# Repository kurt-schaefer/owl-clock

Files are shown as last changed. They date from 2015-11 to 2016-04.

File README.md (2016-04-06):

# owl-clock
2015 Christmas Project

I built six of these owl clocks in the run up to Christmas 2015.
It uses edge lit acrylic sheets to act as psudo Nixie Tubes. The clock uses an ATMEGA328p at it's core. The display is powered but 40 [WS2812b] (https://www.adafruit.com/datasheets/WS2812B.pdf) RGB leds.
I have a [blog post] (https://retrotechjournal.com/2016/04/04/plexitube-owl-clock/) with a longer write up of the project.

Image
-----------

Owl Clock

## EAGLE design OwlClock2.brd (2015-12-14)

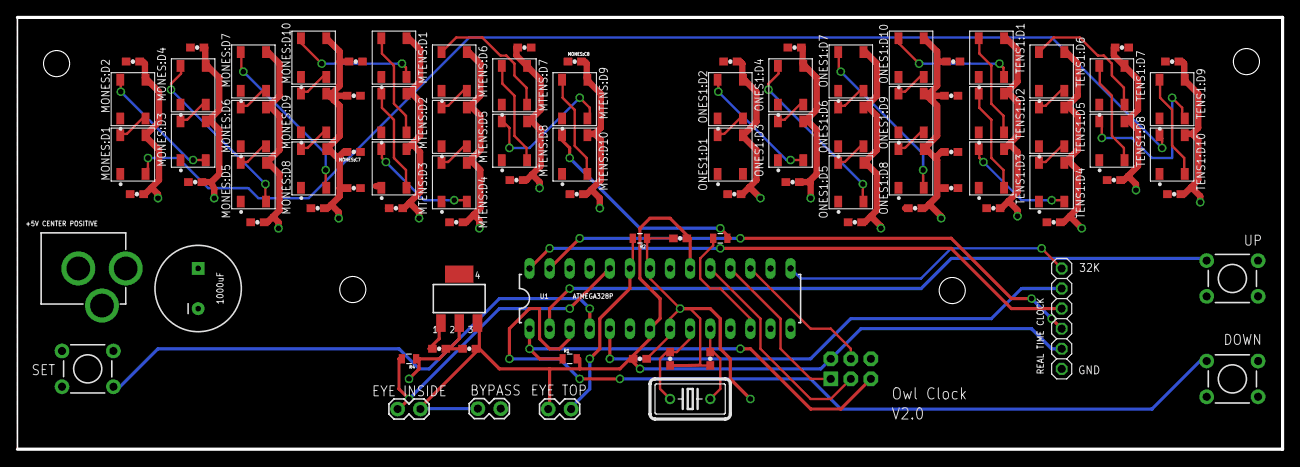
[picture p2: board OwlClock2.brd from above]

Board: 2 copper layers, 160.0 x 54.6 mm, 99 parts (0 on the bottom side), 59 nets.

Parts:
C1, C2: 22pF; 0603-CAP
C3, C4: 0.1uF; 0603-CAP
C5: 1000uF; CPOL-RADIAL-1000UF-25V
C6, C7: 1uF; 0603-CAP
DOWN: SWITCH-MOMENTARY-2PTH; TACTILE-PTH
IC1: MCP1703DB; SOT223
J1: AVR_SPI_PRG_6NS; 2X3-NS
J2: POWER_JACKPTH; POWER_JACK_PTH
JP1: REAL TIME CLOCK; 1X06
MONES:C1, MONES:C2, MONES:C3, MONES:C4, MONES:C5, MONES:C6, MONES:C7, MONES:C8: 0.1uF; 0603-CAP
MONES:D1, MONES:D2, MONES:D3, MONES:D4, MONES:D5, MONES:D6, MONES:D7, MONES:D8, MONES:D9, MONES:D10: WS2812B
MTENS:C1, MTENS:C2, MTENS:C3, MTENS:C4, MTENS:C5, MTENS:C6, MTENS:C7, MTENS:C8: 0.1uF; 0603-CAP
MTENS:D1, MTENS:D2, MTENS:D3, MTENS:D4, MTENS:D5, MTENS:D6, MTENS:D7, MTENS:D8, MTENS:D9, MTENS:D10: WS2812B
ONES1:C1, ONES1:C2, ONES1:C3, ONES1:C4, ONES1:C5, ONES1:C6, ONES1:C7, ONES1:C8: 0.1uF; 0603-CAP
ONES1:D1, ONES1:D2, ONES1:D3, ONES1:D4, ONES1:D5, ONES1:D6, ONES1:D7, ONES1:D8, ONES1:D9, ONES1:D10: WS2812B
PHOTO_INSIDE: M02LOCK; 1X02_LOCK
PHOTO_TOP: M02LOCK; 1X02_LOCK
Q1: 16Mhz; HC18U-V
R1, R2, R4: 10k; 0805
R3: 470; 0805
SET: SWITCH-MOMENTARY-2PTH; TACTILE-PTH
SUPPLY_BYPASS: M02LOCK; 1X02_LOCK
TENS1:C1, TENS1:C2, TENS1:C3, TENS1:C4, TENS1:C5, TENS1:C6, TENS1:C7, TENS1:C8: 0.1uF; 0603-CAP
TENS1:D1, TENS1:D2, TENS1:D3, TENS1:D4, TENS1:D5, TENS1:D6, TENS1:D7, TENS1:D8, TENS1:D9, TENS1:D10: WS2812B
U1: ATMEGA328P_PDIP; DIL28-3
U$1, U$2, U$3, U$4: STAND-OFF
UP: SWITCH-MOMENTARY-2PTH; TACTILE-PTH

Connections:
32K: JP1.1, U1.15
!RESET: J1.5, R1.1, U1.1
ADC0: PHOTO_TOP.1, R2.2, U1.23
ADC1: PHOTO_INSIDE.1, R4.2, U1.24
DP0: U1.2, UP.1
DP1: DOWN.1, U1.3
DP2: SET.1, U1.4
GND: C1.1, C2.1, C3.2, C4.2, C5.2, C6.1, C7.1, DOWN.3, IC1.2, J1.6, J2.GND, J2.GNDBREAK, JP1.6, MONES:C1.2, MONES:C2.2, MONES:C3.2, MONES:C4.2, MONES:C5.2, MONES:C6.2, MONES:C7.2, MONES:C8.2, MONES:D1.3, MONES:D2.3, MONES:D3.3, MONES:D4.3, MONES:D5.3, MONES:D6.3, MONES:D7.3, MONES:D8.3, MONES:D9.3, MONES:D10.3, MTENS:C1.2, MTENS:C2.2, MTENS:C3.2, MTENS:C4.2, MTENS:C5.2, MTENS:C6.2, MTENS:C7.2, MTENS:C8.2, MTENS:D1.3, MTENS:D2.3, MTENS:D3.3, MTENS:D4.3, MTENS:D5.3, MTENS:D6.3, MTENS:D7.3, MTENS:D8.3, MTENS:D9.3, MTENS:D10.3, ONES1:C1.2, ONES1:C2.2, ONES1:C3.2, ONES1:C4.2, ONES1:C5.2, ONES1:C6.2, ONES1:C7.2, ONES1:C8.2, ONES1:D1.3, ONES1:D2.3, ONES1:D3.3, ONES1:D4.3, ONES1:D5.3, ONES1:D6.3, ONES1:D7.3, ONES1:D8.3, ONES1:D9.3, ONES1:D10.3, R2.1, R4.1, SET.3, TENS1:C1.2, TENS1:C2.2, TENS1:C3.2, TENS1:C4.2, TENS1:C5.2, TENS1:C6.2, TENS1:C7.2, TENS1:C8.2, TENS1:D1.3, TENS1:D2.3, TENS1:D3.3, TENS1:D4.3, TENS1:D5.3, TENS1:D6.3, TENS1:D7.3, TENS1:D8.3, TENS1:D9.3, TENS1:D10.3, U1.8, U1.22, UP.3
MISO: J1.1, U1.18
MONES:N$1: MONES:D2.4, MONES:D3.2
MONES:N$5: MONES:D1.4, MONES:D2.2
MONES:N$6: MONES:D3.4, MONES:D4.2
MONES:N$7: MONES:D4.4, MONES:D5.2
MONES:N$9: MONES:D5.4, MONES:D6.2
MONES:N$10: MONES:D6.4, MONES:D7.2
MONES:N$12: MONES:D7.4, MONES:D8.2
MONES:N$13: MONES:D8.4, MONES:D9.2
MONES:N$15: MONES:D9.4, MONES:D10.2
MOSI: J1.4, U1.17
MTENS:N$1: MTENS:D2.4, MTENS:D3.2
MTENS:N$5: MTENS:D1.4, MTENS:D2.2
MTENS:N$6: MTENS:D3.4, MTENS:D4.2
MTENS:N$7: MTENS:D4.4, MTENS:D5.2
MTENS:N$9: MTENS:D5.4, MTENS:D6.2
MTENS:N$10: MTENS:D6.4, MTENS:D7.2
MTENS:N$12: MTENS:D7.4, MTENS:D8.2
MTENS:N$13: MTENS:D8.4, MTENS:D9.2
MTENS:N$15: MTENS:D9.4, MTENS:D10.2
M_ONES_OUT: MONES:D1.2, TENS1:D10.4
M_TENS_IN: MTENS:D10.4, R3.2
unnamed: MONES:D10.4, MTENS:D1.2
unnamed: R3.1, U1.12
unnamed: ONES1:D10.4, TENS1:D1.2
unnamed: C1.2, Q1.2, U1.9
unnamed: C2.2, Q1.1, U1.10
ONES1:N$1: ONES1:D2.4, ONES1:D3.2
ONES1:N$5: ONES1:D1.4, ONES1:D2.2
ONES1:N$6: ONES1:D3.4, ONES1:D4.2
ONES1:N$7: ONES1:D4.4, ONES1:D5.2
ONES1:N$9: ONES1:D5.4, ONES1:D6.2
ONES1:N$10: ONES1:D6.4, ONES1:D7.2
ONES1:N$12: ONES1:D7.4, ONES1:D8.2
ONES1:N$13: ONES1:D8.4, ONES1:D9.2
ONES1:N$15: ONES1:D9.4, ONES1:D10.2
SCK: J1.3, U1.19
SCL: JP1.3, U1.28
SDA: JP1.4, U1.27
SQW: JP1.2, U1.5
TENS1:N$1: TENS1:D2.4, TENS1:D3.2
TENS1:N$5: TENS1:D1.4, TENS1:D2.2
TENS1:N$6: TENS1:D3.4, TENS1:D4.2
TENS1:N$7: TENS1:D4.4, TENS1:D5.2
TENS1:N$9: TENS1:D5.4, TENS1:D6.2
TENS1:N$10: TENS1:D6.4, TENS1:D7.2
TENS1:N$12: TENS1:D7.4, TENS1:D8.2
TENS1:N$13: TENS1:D8.4, TENS1:D9.2
TENS1:N$15: TENS1:D9.4, TENS1:D10.2
VCC: C5.1, C7.2, IC1.1, J2.PWR, MONES:C1.1, MONES:C2.1, MONES:C3.1, MONES:C4.1, MONES:C5.1, MONES:C6.1, MONES:C7.1, MONES:C8.1, MONES:D1.1, MONES:D2.1, MONES:D3.1, MONES:D4.1, MONES:D5.1, MONES:D6.1, MONES:D7.1, MONES:D8.1, MONES:D9.1, MONES:D10.1, MTENS:C1.1, MTENS:C2.1, MTENS:C3.1, MTENS:C4.1, MTENS:C5.1, MTENS:C6.1, MTENS:C7.1, MTENS:C8.1, MTENS:D1.1, MTENS:D2.1, MTENS:D3.1, MTENS:D4.1, MTENS:D5.1, MTENS:D6.1, MTENS:D7.1, MTENS:D8.1, MTENS:D9.1, MTENS:D10.1, ONES1:C1.1, ONES1:C2.1, ONES1:C3.1, ONES1:C4.1, ONES1:C5.1, ONES1:C6.1, ONES1:C7.1, ONES1:C8.1, ONES1:D1.1, ONES1:D2.1, ONES1:D3.1, ONES1:D4.1, ONES1:D5.1, ONES1:D6.1, ONES1:D7.1, ONES1:D8.1, ONES1:D9.1, ONES1:D10.1, SUPPLY_BYPASS.2, TENS1:C1.1, TENS1:C2.1, TENS1:C3.1, TENS1:C4.1, TENS1:C5.1, TENS1:C6.1, TENS1:C7.1, TENS1:C8.1, TENS1:D1.1, TENS1:D2.1, TENS1:D3.1, TENS1:D4.1, TENS1:D5.1, TENS1:D6.1, TENS1:D7.1, TENS1:D8.1, TENS1:D9.1, TENS1:D10.1
VSS: C3.1, C4.1, C6.2, IC1.3, J1.2, JP1.5, PHOTO_INSIDE.2, PHOTO_TOP.2, R1.2, SUPPLY_BYPASS.1, U1.7, U1.20

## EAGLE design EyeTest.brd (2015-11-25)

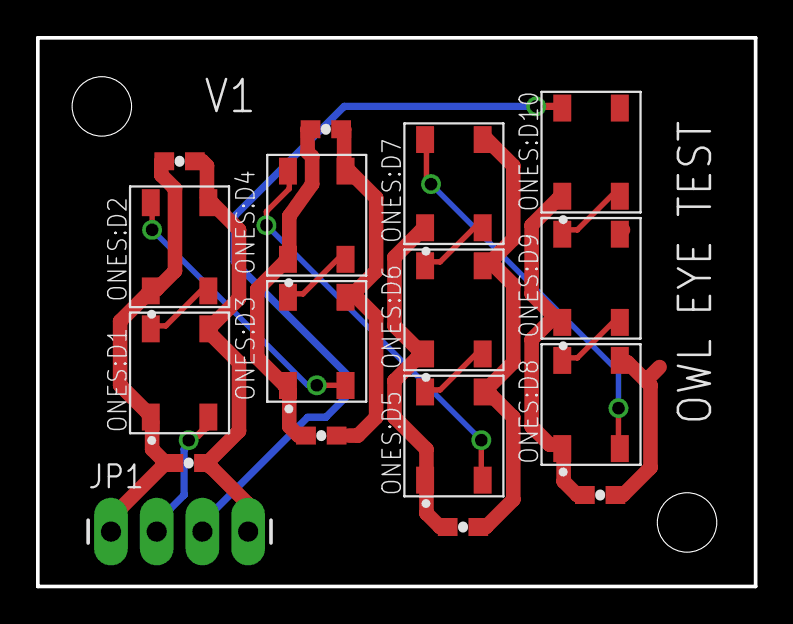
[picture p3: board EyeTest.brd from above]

Board: 2 copper layers, 39.9 x 30.5 mm, 19 parts (0 on the bottom side), 13 nets.

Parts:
JP1: 1X04_LONGPADS
ONES:C1, ONES:C2, ONES:C3, ONES:C4, ONES:C5, ONES:C6: 0.1uF; 0603-CAP
ONES:D1, ONES:D2, ONES:D3, ONES:D4, ONES:D5, ONES:D6, ONES:D7, ONES:D8, ONES:D9, ONES:D10: WS2812B
U$1, U$2: STAND-OFF

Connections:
DIN: JP1.3, ONES:D10.4
DOUT: JP1.2, ONES:D1.2
GND: JP1.4, ONES:C1.2, ONES:C2.2, ONES:C3.2, ONES:C4.2, ONES:C5.2, ONES:C6.2, ONES:D1.3, ONES:D2.3, ONES:D3.3, ONES:D4.3, ONES:D5.3, ONES:D6.3, ONES:D7.3, ONES:D8.3, ONES:D9.3, ONES:D10.3
ONES:N$1: ONES:D2.4, ONES:D3.2
ONES:N$5: ONES:D1.4, ONES:D2.2
ONES:N$6: ONES:D3.4, ONES:D4.2
ONES:N$7: ONES:D4.4, ONES:D5.2
ONES:N$9: ONES:D5.4, ONES:D6.2
ONES:N$10: ONES:D6.4, ONES:D7.2
ONES:N$12: ONES:D7.4, ONES:D8.2
ONES:N$13: ONES:D8.4, ONES:D9.2
ONES:N$15: ONES:D9.4, ONES:D10.2
VCC: JP1.1, ONES:C1.1, ONES:C2.1, ONES:C3.1, ONES:C4.1, ONES:C5.1, ONES:C6.1, ONES:D1.1, ONES:D2.1, ONES:D3.1, ONES:D4.1, ONES:D5.1, ONES:D6.1, ONES:D7.1, ONES:D8.1, ONES:D9.1, ONES:D10.1

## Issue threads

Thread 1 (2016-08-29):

Update license please

burdickjp, 2016-08-29:
Hey, Kurt!
I want to make DROs for me mill and lathe using plexitubes because they're awesome. I appreciate that you've got a github for the project, because it allows me to link back to it and provide proper attribution.
I noticed that your license is software related and this is a hardware project.
Could you switch to a license compliant with the open source hardware guidelines?
http://www.oshwa.org/

I tend to use the Cern OHL:
http://www.ohwr.org/projects/cernohl/wiki

Thank you, again for documenting such an awesome project and taking the time to releasing it as open source.

kurt-schaefer, 2016-08-30:
Wow, I'd love to see a mill with Plexitube DRO's!   That sounds fun.   Yes sorry I was mostly using github for the software side.  I've never released open source hardware before.  I'll read though the guidelines and update the license.  I wrote the build up as a "oh I built this" not as a full on "here's every detail on how to built it yourself".  So just be aware of that.   Refining/documenting/testing a project to a "this is DIY instructions" level is a  project unto itself.  Doing these Christmas Projects I always have a super short schedule so time for iteration is pretty much zero.

Let me know if you manage to get something up and running!   If you get it written up I'd be happy to add a link over to it from my blog. I'd love to see some other projects spring from this one.

I'm super busy right this second, but Wed. night I should have time to read up on the license stuff and update it.  I should know about that stuff anyway since I do a modest amount of hardware design.

burdickjp, 2016-08-30:
Thank you, and glad I can help with the licensing.
Looking through Oshwa can be daunting, but in general it just comes down to a preference for working files rather than distribution files. A good example is CAD models rather than STLs for 3d printing parts. STEP files are a good compromise because they can be altered by most CAD programs, but STLs are lossy and don't preserve features.
If you're worried front-to-back about a permissive license which provides a decent blanket to all things you could go with a creative commons license. I prefer stricter OHL licenses because of their focus on releasing working, usable models.

kurt-schaefer, 2016-09-03:
Ok, I added the cernohl.  Let me know how your project goes!

Closed 2016-09-03.

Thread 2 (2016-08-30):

Day of the Week computation not working

kurt-schaefer, 2016-08-30:
I noticed that Mother's day/Father's day were not working.  Further testing of the code in an Arduino simulator confirms that the days of the week code is failing under single precision math.  Since I don't think I'm going to update everyone's clocks I don't know as I'm going to go though the trouble of getting this to work, but I'll file this to document the issue.

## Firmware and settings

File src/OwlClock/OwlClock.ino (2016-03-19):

#include <Adafruit_NeoPixel.h> // https://github.com/adafruit/Adafruit_NeoPixel
#include <DS3232RTC.h>         // http://github.com/JChristensen/DS3232RTC
#include <Time.h>              // http://www.arduino.cc/playground/Code/Time
#include <Wire.h>              // http://arduino.cc/en/Reference/Wire (included with Arduino IDE)
#include <EEPROM.h>
#include "Declarations.h"

// My helper lib that has moon and holiday code in it.
extern "C" {
#include "AstronomicalCalculations.h"
}

#define LIGHT_SENSOR_TOP_ANALOG_IN     A0
#define LIGHT_SENSOR_INSIDE_ANALOG_IN  A1
#define LED_COUNT 40

#define LED_DIG_OUT        6

#define NOT_RUNNING_ON_UNO

#ifdef NOT_RUNNING_ON_UNO
    #define DEBUG_PRINT(x)    Serial.print(x)
    #define DEBUG_PRINTLN(x)  Serial.println(x)
#else
    #define DEBUG_PRINT(x)    {}  
    #define DEBUG_PRINTLN(x ) {} 
#endif

#ifdef RUNNING_ON_UNO
    #define SWITCH_UP_DIG_IN   2
    #define SWITCH_DOWN_DIG_IN 3
    #define SWITCH_SET_DIG_IN  4
#else
// This has up/down reversed from what is silscreened on the boards, but this
// is the "right" way around in term of feel.
    #define SWITCH_UP_DIG_IN   1
    #define SWITCH_DOWN_DIG_IN 0
    #define SWITCH_SET_DIG_IN  2
#endif

// Neo pixel interface for all the LEDS is though the single pin LED_DIG_OUT
Adafruit_NeoPixel leds = Adafruit_NeoPixel(LED_COUNT, LED_DIG_OUT, NEO_GRB + NEO_KHZ800);

// digit to LED index for the clock digits. Tens and Ones are sequenced differently.
static const uint8_t gTensDigit[] = {6, 9, 4, 3, 1, 8, 5, 2, 0, 7};
static const uint8_t gOnesDigit[] = {5, 0, 3, 6, 8, 1, 4, 7, 9, 2};

EEPROMInfo gInfo;
uint32_t gHourTensColor = COLOR_DEFAULT_DIGITS;
uint32_t gHourOnesColor = COLOR_DEFAULT_DIGITS;
uint32_t gMinTensColor  = COLOR_DEFAULT_DIGITS;
uint32_t gMinOnesColor  = COLOR_DEFAULT_DIGITS;

uint8_t gHourTensScale = 0xff;
uint8_t gHourOnesScale = 0xff;
uint8_t gMinTensScale  = 0xff;
uint8_t gMinOnesScale  = 0xff;

uint8_t gDimmingValue = 0xff;

uint32_t gHolidayDigitColor = COLOR_DEFAULT_DIGITS;
uint8_t gDayDisplayType = DAY_TYPE_NORMAL_DAY;
uint8_t gSpecialCharacterType = SPECIAL_CHAR_TYPE_CURRENT_MOON;



#define DEFAULT_GMT_OFFSET -8*60*60;

// To addess each digit use these bases + the above index.
#define HOUR_TENS_BASE    20
#define HOUR_ONES_BASE    30
#define MINUTE_TENS_BASE   0
#define MINUTE_ONES_BASE  10
#define NO_INDEX 255

// The various moon arcs, have digit equivalents, so we list those here.
// The percentages go from upper right to lower left.
#define ZERO_PERCENT_MOON_ARC 20
#define TWENTY_PERCENT_MOON_ARC 25
#define FORTY_PERCENT_MOON_ARC 21
#define SIXTY_PERCENT_MOON_ARC 23
#define EIGHTY_PERCENT_MOON_ARC 28
#define ONE_HUNDRED_PERCENT_MOON_ARC 22

// The other special characters.
#define SUN_OUTLINE 26
#define EYE_OUTLINE 27

#define EYE_SEAK_DURATION 120

#define EEPROM_INFO_ADDRESS 0
#define EEPROM_NEVER_WAS_SET 255
#define EEPROM_INFO_VERSION 1   // Increment this if you change/reorder the EEPROMInfo


#define DEFAULT_LATITUDE 36.3894     // These are burned into the EEPROM on starup/version bump.
#define DEFAULT_LONGITUDE -122.0819

// I wrote a ton of code to compute these sun events, but the code took 24k of program space,
// so instead I'm squeezing the next 100 years of sun events into these arrays.  The
// value are two bit offsets from their base value.  So 4 years per byte. That makes it
// simple to do the progmem lookup for the correct byte and mask from there.

const uint8_t springEquinoxArray[] PROGMEM = { 85, 85, 85, 85, 85, 85, 85, 84, 84, 84, 84, 84,
                                               84, 84, 84, 80, 80, 80, 80, 80, 80, 165, 165, 149, 149, };
const uint8_t summerSolsticeArray[] PROGMEM = { 84, 84, 84, 84, 84, 84, 80, 80, 80, 80, 80, 80, 
                                                80, 64, 64, 64, 64, 64, 64, 64, 0, 85, 85, 85, 85, };
const uint8_t fallEquinoxArray[] PROGMEM = { 165, 165, 165, 149, 149, 149, 149, 149, 149, 149, 149, 85, 85, 
                                             85, 85, 85, 85, 85, 85, 84, 84, 169, 169, 169, 169, };
const uint8_t winterSolsticeArray[] PROGMEM = { 149, 149, 149, 149, 149, 149, 149, 85, 85, 85, 85, 85, 85, 85, 
                                                85, 85, 84, 84, 84, 84, 84, 169, 169, 169, 165, };

#define SPRING_EQUINOX_DAY_BASE 19
#define SUMMER_SOLSTICE_DAY_BASE 20
#define FALL_EQUINOX_DAY_BASE 21
#define WINTER_SOLSTICE_DAY_BASE 20

#define SUN_EVENT_YEAR_BASE 2016
#define SUN_EVENT_YEAR_RANGE 100

// This should be passed one of the PROGMEM solar event arrays above with the matching DAY_BASE
uint8_t unpackSunEventDay(const uint8_t *pgmArray, uint8_t dayBase, int year)
{
  // If the year is in the past, something has gone wrong, and we don't 
  // care the the solar events are wrong.
  if (year < SUN_EVENT_YEAR_BASE) {
    year = SUN_EVENT_YEAR_BASE;
  }
  
  int index = (year - SUN_EVENT_YEAR_BASE)/4;
  int shift = ((year - SUN_EVENT_YEAR_BASE)%4)*2;

  // To keep things from crashing 100 years from now we loop around
  // after that time the sun events will be incorrect, but all the people
  // I have given the clocks to will be dead so no one will care.
  index = index%SUN_EVENT_YEAR_RANGE;

  uint8_t mask = 3 << shift;
  
  return ((pgm_read_byte(&pgmArray[index]) & mask) >> shift) + dayBase;
}

// This looks up a display digit based on the base and the ordering arrays.
uint8_t ledIndex(uint8_t base, uint8_t digit)
{
    // Possibly make this do PROGMEM lookups
    if (base == MINUTE_ONES_BASE || base == HOUR_ONES_BASE) {
        return base + gOnesDigit[digit];
    }
    return base + gTensDigit[digit];
}

void setup(void)
{
    // Add pullup resistors to all the switch inputs.
    pinMode(SWITCH_UP_DIG_IN, INPUT_PULLUP);
    pinMode(SWITCH_DOWN_DIG_IN, INPUT_PULLUP);
    pinMode(SWITCH_SET_DIG_IN, INPUT_PULLUP);
  

  //setSyncProvider() causes the Time library to synchronize with the
  //external RTC by calling RTC.get() every five minutes by default.
  setSyncProvider(RTC.get);

#ifdef RUNNING_ON_UNO
   Serial.begin(19200);
   if (timeStatus() != timeSet) {
     Serial.print(F("RTC Sync setup failed."));
   }
#endif
  readAndValidateEEPromInfo();
 
  leds.begin();
  clearLeds();
  leds.show();

  // Restore display mode type.
  time_t t = now() + gInfo.gmtOffsetInSeconds;
  gDayDisplayType = computeDayTypeForTime(t, &gSpecialCharacterType);
}

void
readAndValidateEEPromInfo()
{
    EEPROM.get(EEPROM_INFO_ADDRESS, gInfo);

    // If we have never saved this info off to eeprom
    // we have to assume the current clock is ok and recompute everything based on that.
    if (gInfo.version != EEPROM_INFO_VERSION) {
        gInfo.gmtOffsetInSeconds = DEFAULT_GMT_OFFSET;
        time_t t = now() + gInfo.gmtOffsetInSeconds;        
        writeEEProm(t);
    }

    //        bool oscStopped(bool clearOSF = true);  //defaults to clear the OSF bit if argument not supplied
    // TODO: Maybe I should add some code that blinks if the oscStopped flag has been set on reboot.
}

void
writeEEProm(time_t t)
{
    gInfo.version = EEPROM_INFO_VERSION;
    gInfo.year = (unsigned short)year(t);
    gInfo.month = month(t);
    gInfo.day = day(t);

    EEPROM.put(EEPROM_INFO_ADDRESS, gInfo);
}

uint8_t computeDayTypeForTime(time_t t, uint8_t *specialCharacterTypePtr)
{
    int currentYear = year(t);
    int currentMonth = month(t);
    int currentDay = day(t);

    (*specialCharacterTypePtr) = SPECIAL_CHAR_TYPE_CURRENT_MOON;
    uint8_t dayType = DAY_TYPE_NORMAL_DAY;

    unsigned char easterMonth = 0;
    unsigned char easterDay = 0;

    // If this month might have Easer in it we compute Easter.
    if (currentMonth == MARCH || currentMonth == APRIL) {
        easterForYear(currentYear, &easterMonth, &easterDay);
    }

    if (currentMonth == JANUARY) {
        if (currentDay == 3) { // J. R. R. Tolkien's birthday.
            (*specialCharacterTypePtr) = SPECIAL_CHAR_TYPE_SAURON_EYE;
            gHolidayDigitColor = COLOR_RED;
            dayType = DAY_TYPE_TOLKIENS_BIRTHDAY;
        } else  if (currentDay == 27) { // Kurt S. Green
            gHolidayDigitColor = COLOR_GREEN;
            dayType = DAY_TYPE_BIRTHDAY;
        }
    } else if (currentMonth == FEBRUARY) {
        if (currentDay == 2) { // Ground Hog Day
            
        } else if (currentDay == 3) { // Cheryl Green
            gHolidayDigitColor = COLOR_GREEN;
            dayType = DAY_TYPE_BIRTHDAY;
        } else if (currentDay == 12) { // Lawrence Green.
            gHolidayDigitColor = COLOR_GREEN;
            dayType = DAY_TYPE_BIRTHDAY;
        } else if (currentDay == 14) { // Valentine's Day
            gHolidayDigitColor = COLOR_PINK;
            (*specialCharacterTypePtr) = SPECIAL_CHAR_TYPE_BEATING_HEART;
            dayType = DAY_TYPE_VALENTINES_DAY;
        }
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
void loop()
{
    DEBUG_PRINTLN(F("LOOP"));
    // If the user hits the set button, we go though the setup sequence.
    if (digitalRead(SWITCH_SET_DIG_IN) == false) {
        delay(50);
        performUserSetupSequence();
    }

    if (digitalRead(SWITCH_UP_DIG_IN) == false) {
        showOpticalTheremin();
    }
    if (digitalRead(SWITCH_DOWN_DIG_IN) == false) {
        showTemperature();
    }
    
    time_t t = now() + gInfo.gmtOffsetInSeconds;
    
    checkForDisplayModeChange(t);
    showTimeUsingCurrentDisplayMode(t);
    static uint8_t count = 0;
    count++;
    if (!(count%4)) { 
        updateBrightness();
    }
}

void clearLeds()
{
    for (int i=0; i<LED_COUNT; i++) {
        leds.setPixelColor(i, 0);
    }
}

void clearSpecialCharacterLeds()
{
    leds.setPixelColor(ledIndex(HOUR_TENS_BASE, 0), 0);
    for (int i=3; i<10; ++i ) {
        leds.setPixelColor(ledIndex(HOUR_TENS_BASE, i), 0);
    }
}

void setAllDigits(uint8_t base, uint32_t color)
{
    if (base == NO_INDEX) {
        return;
    }
    for (uint8_t digit = 0; digit < 10; ++digit) {
        leds.setPixelColor(ledIndex(base, digit), color);
    }
}


void displayValue(int value,
                  uint8_t digitOnesBase,
                  uint8_t digitTensBase,
                  uint8_t digitHundredsBase,
                  uint8_t digitThousandsBase,
                  uint8_t colorScale,
                  uint8_t digitType)
{
    uint32_t color = (value < 0) ? leds.Color(0, 128, 255) : leds.Color(254, 120, 0);
    uint32_t colorBlack = 0;

    clearSpecialCharacterLeds();

    bool isPM = false;
    if (digitType == DIGIT_TYPE_HOURS) {
        if (value >= 12) {
            isPM = true;
        }
        value = twelveHourValueFrom24HourTime(value);
    }

    value = abs(value);
    
    uint8_t onesDigit = value%10;
    value = value/10;
    uint8_t tensDigit = value%10;
    value = value/10;
    uint8_t hundredsDigit = value%10;
    value = value/10;
    uint8_t thousandsDigit = value%10;

    // If we're showing minutes, we always show the leading zeros.
    bool foundNonZeroDigit = digitType == DIGIT_TYPE_MINUTES;

    // Clear any digits we will be writing into.
    setAllDigits(digitOnesBase, 0);
    setAllDigits(digitTensBase, 0);
    setAllDigits(digitHundredsBase, 0);
    setAllDigits(digitThousandsBase, 0);

    // As a "PM Indicator" we display a big circle behind the hour tens digit.
    // In either the "first half of the 24 hour clock face" or seconds half.
    if (digitType == DIGIT_TYPE_HOURS) {
        if (isPM) {
            leds.setPixelColor(ONE_HUNDRED_PERCENT_MOON_ARC, leds.Color(255, 5, 5));
        } else {
            leds.setPixelColor(ZERO_PERCENT_MOON_ARC, leds.Color(255, 5, 5));
        }
    } else if (digitType == DIGIT_TYPE_MONTH) {
        // For months we show a moon
        leds.setPixelColor(ONE_HUNDRED_PERCENT_MOON_ARC, leds.Color(255, 248, 209));
        leds.setPixelColor(EIGHTY_PERCENT_MOON_ARC, leds.Color(255, 248, 209));
    } else if (digitType == DIGIT_TYPE_DAY) {
        // For days we show a sun.
        leds.setPixelColor(ONE_HUNDRED_PERCENT_MOON_ARC, leds.Color(254, 120, 0));
        leds.setPixelColor(ZERO_PERCENT_MOON_ARC, leds.Color(254, 120, 0));
        leds.setPixelColor(SUN_OUTLINE, leds.Color(254, 120, 0));
    }

    color = scaleColor(color, colorScale);
    
    foundNonZeroDigit |= thousandsDigit != 0;
    if (digitThousandsBase != NO_INDEX) {
        leds.setPixelColor(ledIndex(digitThousandsBase, thousandsDigit), (foundNonZeroDigit) ? color : colorBlack);
    }

    foundNonZeroDigit |= hundredsDigit != 0;
    if (digitHundredsBase != NO_INDEX) {
        leds.setPixelColor(ledIndex(digitHundredsBase, hundredsDigit), (foundNonZeroDigit) ? color : colorBlack);
    }

    foundNonZeroDigit |= tensDigit != 0;
    if (digitTensBase != NO_INDEX) {
        leds.setPixelColor(ledIndex(digitTensBase, tensDigit), (foundNonZeroDigit) ? color : colorBlack);
    }

    // We never show nothing, so if we've gotten all the way down here
    // and the last digit is 0 we still show it.
    foundNonZeroDigit |= onesDigit != 0;
    if (digitOnesBase != NO_INDEX) {
        leds.setPixelColor(ledIndex(digitOnesBase, onesDigit), color);
    }

    leds.show();
}

#define USER_TIMEOUT 1
#define USER_HIT_SET 2

// Simple color scale so we can do color brightness animations.
uint32_t scaleColor(uint32_t color, uint8_t scale)
{
    // The cast chops off the high bits without having to mask them.
    uint8_t r = (uint8_t)(color >> 16);
    uint8_t g = (uint8_t)(color >> 8);
    uint8_t b = (uint8_t)(color);
   
    r = (r*scale) >> 8;
    g = (g*scale) >> 8;
    b = (b*scale) >> 8;

    return ((uint32_t )r << 16) | ((uint32_t)g << 8) | (uint32_t)b;
}
    

uint8_t setValueUsingButtons(int *currentValue, int minValue, int maxValue,
                          uint8_t digitOnesBase,
                          uint8_t digitTensBase,
                          uint8_t digitHundredsBase,
                          uint8_t digitThousandsBase,
                          uint8_t digitType)
{
    SharedEventState eventState;
    ButtonInfo setButtonInfo;
    ButtonInfo upButtonInfo;
    ButtonInfo downButtonInfo;
    
    clearSharedEventState(&eventState);
    initializeButtonInfo(&setButtonInfo, SWITCH_SET_DIG_IN, false);
    initializeButtonInfo(&upButtonInfo, SWITCH_UP_DIG_IN, true);
    initializeButtonInfo(&downButtonInfo, SWITCH_DOWN_DIG_IN, true);

    displayValue(*currentValue, digitOnesBase, digitTensBase, digitHundredsBase, digitThousandsBase, 255, digitType);

    time_t startTime = millis();
    time_t currentTime = startTime;
    time_t mostRecentEventTime = currentTime;
  
    uint8_t event;
    uint8_t colorScale;
  
    do {
        currentTime = millis();

        // Compute a saw tooth that cycles every second from 255 down to 205 and then back up to 255
        // so we can "blink" the digits you are setting in a way that's familar to clock setting people.
        colorScale = 255 - (((currentTime - startTime)%500)/2);
        //   DEBUG_PRINT(F("scale: "));
        //   DEBUG_PRINTLN(colorScale);
        displayValue(*currentValue, digitOnesBase, digitTensBase, digitHundredsBase, digitThousandsBase, colorScale, digitType);
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

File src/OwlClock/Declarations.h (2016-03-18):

// This is the set of things we keep track of in eeprom.  This is mostly 
// so we can record peruser info, and only have to compute the various
// holidays once a year.
typedef struct {
  unsigned char version;  // incremented if the info struct changes, also used to check
                          // never having been written state.
  
  unsigned short year;    // Most recent handled year, year all the holidays are computed for.
  unsigned char month;    // Most recently handled month.
  unsigned char day;      // Most recently handled day.

  int gmtOffsetInSeconds; 
} EEPROMInfo;

// This is used to keep track of individual button state during button input/auto repeat, etc.

#define BUTTON_PRESSED     0
#define BUTTON_RELEASED    1
#define BUTTON_AUTO_REPEAT 2
#define BUTTON_NO_EVENT    3

#define BUTTON_STATE_MOST_RECENT_STATE   (1 << 0)
#define BUTTON_STATE_OWNS_START_TIME     (1 << 1)
#define BUTTON_STATE_CAN_AUTO_REPEAT     (1 << 2)
#define BUTTON_STATE_OFFICALLY_PRESSED   (1 << 3)

typedef struct
{
    uint8_t state;
    uint8_t pin;
} ButtonInfo;

// Because we do some tricky things with color/indicating AM PM, forcing leading
// zeros, etc. It is useful for us to have a digit type during display.
#define DIGIT_TYPE_HOURS      0
#define DIGIT_TYPE_MINUTES    1
#define DIGIT_TYPE_GMT_OFFSET 2
#define DIGIT_TYPE_YEAR       3
#define DIGIT_TYPE_MONTH      4
#define DIGIT_TYPE_DAY        5

#define BUTTON_DEBOUNCE_INTERVAL 50
#define MAX_AUTO_REPEAT_INTERVAL 350
#define MIN_AUTO_REPEAT_INTERVAL 200
#define AUTO_REPEAT_RAMP_DELAY 2
#define AUTO_REPEAT_RAMP_STEP  50
#define USER_INPUT_TIMEOUT     10000

typedef struct
{
    time_t buttonPressTime;
    time_t mostRecentAutoRepeatTime;
    short autoRepeatCount;
    short autoRepeatInterval;
} SharedEventState;

#define SPECIAL_CHAR_TYPE_SPRING_EQUINOX    0
#define SPECIAL_CHAR_TYPE_SUMMER_SOLSTICE   1
#define SPECIAL_CHAR_TYPE_FALL_EQUINOX      2
#define SPECIAL_CHAR_TYPE_WINTER_SOLSTICE   3
#define SPECIAL_CHAR_TYPE_CURRENT_MOON      4
#define SPECIAL_CHAR_TYPE_GOLDEN_RING       5
#define SPECIAL_CHAR_TYPE_SPINNING_GLOBE    6
#define SPECIAL_CHAR_TYPE_MONSTER_EYE       7
#define SPECIAL_CHAR_TYPE_SAURON_EYE        8
#define SPECIAL_CHAR_TYPE_BEATING_HEART     9 // No Implemented yet.
#define SPECIAL_CHAR_TYPE_SPINNING_ORNAMENT 10

#define DAY_TYPE_NORMAL_DAY             0
#define DAY_TYPE_BIRTHDAY               1
#define DAY_TYPE_FLAG_DAY               2
#define DAY_TYPE_MIDNIGHT_COUNTDOWN_DAY 3
#define DAY_TYPE_VALENTINES_DAY         4
#define DAY_TYPE_COLOR_HOLIDAY          5 // These are defined by a color + special char.
#define DAY_TYPE_EASTER                 6
#define DAY_TYPE_TOLKIENS_BIRTHDAY      7
#define DAY_TYPE_HALLOWEEN              8
#define DAY_TYPE_APRIL_FOOLS            9

#define FIREWORKS_STATE_WHITE_FLASH 0
#define FIREWORKS_STATE_SOLID_COLOR_FADE 1
#define FIREWORKS_STATE_BETWEEN_FLASHES 2

#define COLOR_DEFAULT_DIGITS 0xff0000
#define COLOR_GOLD 0xfe7000
#define COLOR_COPPER 0xff3000
#define COLOR_PINK 0xfe0032
#define COLOR_GREEN 0x00ff00
#define COLOR_BLUE  0x0000ff
#define COLOR_RED 0xff0000
#define COLOR_YELLOW 0xfea100
#define COLOR_TURQUOISE 0x00ffff
#define COLOR_ORANGE 0xfe1a00
#define COLOR_PURPLE 0xff00ff
#define COLOR_MOON_BRIGHT 0xfff8d1
#define COLOR_MOON_DIM 0x0f120d
#define COLOR_EYE_GREEN 0x00c800
#define COLOR_WHITE 0xffffff
#define COLOR_ALMOST_WHITE 0xfffffe


#define MIN_DIMMING_SCALE 64

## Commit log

2015-11-19 Very inital version of the schematic. Almost no layout as yet.
    [OwlClock.brd, OwlClock.sch]
2015-11-22 Start work on doing eye layout in a seprate file so I can multi import later.
    [OwlEye.brd, OwlEye.sch]
2015-11-22 Starting to route using the second layer and vias
    [OwlEye.brd]
2015-11-22 After smashing and text adjustment
    [OwlEye.brd]
2015-11-22 Removed the extra caps
    [OwlEye.brd, OwlEye.sch]
2015-11-23 Use Import to make a two eye schematic, add power regulator, basic routing.
    [MOwlEye.brd, MOwlEye.sch, OwlClock2.brd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]
2015-11-23 Add vias for led grounds, clean up switches, fix up the supply caps.
    [OwlClock2.brd, OwlClock2.sch]
2015-11-23 More work on ground plane, fixed ground vias for led power.
    [OwlClock2.brd]
2015-11-24 Add power plane fix board outline, finish first pass of routing.
    [OwlClock2.brd, OwlClock2.sch]
2015-11-24 Finish up labels and cleanup, pass design rules check
    [OwlClock2.brd, OwlClock2.sch]
2015-11-24 Move Via Stop Limit up to 28mils to tent vias
    [OwlClock2.brd]
2015-11-25 Add a tiny test board so I can try reflowing on a smaller board first.
    [EyeTest.brd, EyeTest.sch]
2015-11-25 Fix problem where real time clock was connected to the wrong supply
    [OwlClock2.brd, OwlClock2.sch]
2015-11-28 Add owl logo to board, start adding explicit labels to components.
    [OwlClock2.brd]
2015-11-29 Inital rework of eye layers and masks to fit board geometry.
2015-11-29 Start work on the led masks
2015-12-03 Design the backing plate and front plate.
2015-12-06 Add the led indexing
2015-12-14 Finally add the owlLogo to the boards and add a regulator bypass block.
    [OwlClock2.brd, OwlClock2.sch]
2016-02-01 Fix 24 hour to 12 hour clock conversion.
    [OwlClock.ino]
2016-02-18 Add a RLE version of storing the solar events for the next 100 years. This should be replaced with a direct access 4 values per byte direct packing next.
    [OwlClock.ino]
2016-02-25 Take a first stab at clock setting with auto repeat. Add a define for testing on an UNO with serial printing.
2016-02-27 Add moon and sun indicators when setting the month/day. Swap up/down to be more intuitive. Adjust color pulsing.
    [OwlClock.ino]
2016-02-28 Fix time setting so it doen't mess up the year.
    [OwlClock.ino]
2016-02-28 update the ramping code a little, and fix up the eeprom saving stuff. Now the setting code fully works.
    [Declarations.h, OwlClock.ino]
2016-02-28 Switch to direct indexing of he special characters.
2016-03-14 Rewrite the fireworks. Adjust the dimming spring constant a bit.
2016-03-14 Add temperature display and annaversary
2016-03-18 Fix the temperature output to show deg F.
    [OwlClock.ino]
2016-03-19 Adjust colors for temps, this is the version that M&D have currently
2016-03-19 Fix eeprom reading/writing bug and remove exta smarts about adjusting gmt automatically if you change the hour buy one, also fix issue where incorrect hour could be shown as you change hours during t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
    [OwlClock.ino]
2016-04-03 Remove the old out of date OwlClock.brd/.sch
    [OwlClock.brd, OwlClock.sch]

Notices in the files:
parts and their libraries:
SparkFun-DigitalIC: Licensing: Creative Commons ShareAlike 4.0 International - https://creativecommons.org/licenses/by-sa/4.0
